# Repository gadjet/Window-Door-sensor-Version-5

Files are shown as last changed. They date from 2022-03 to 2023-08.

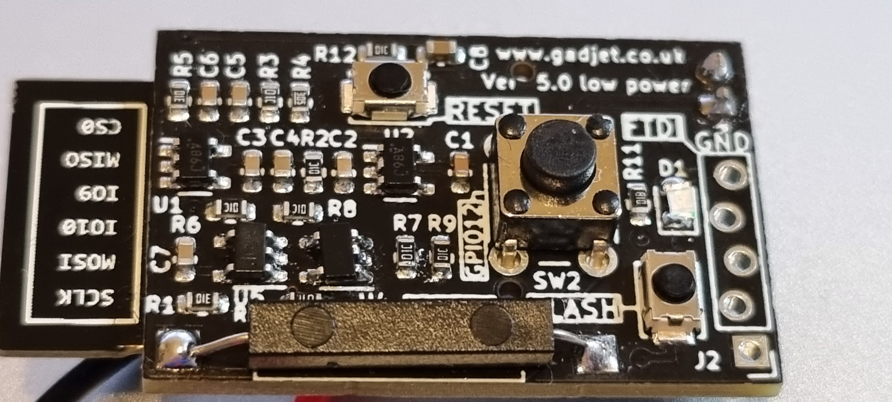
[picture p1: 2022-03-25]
V5_Assembled.jpg

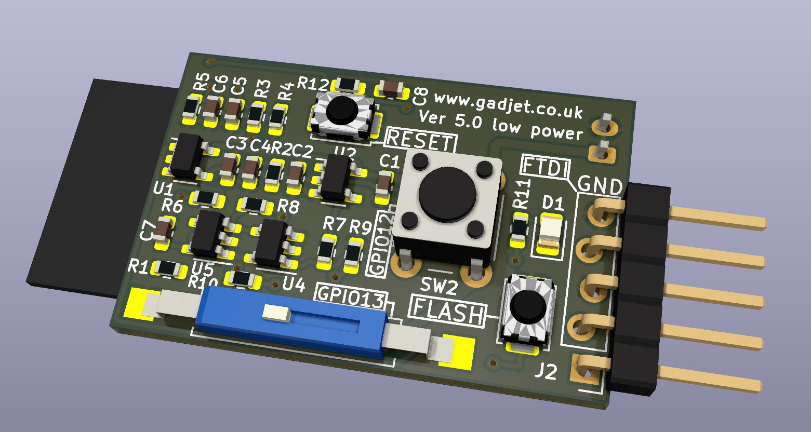
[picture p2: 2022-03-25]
3D render V5.jpg

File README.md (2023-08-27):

# Window-Door-sensor-Version-5

# I have found an error in the BOM file for the PCBA, U4 has the wrong LSC part number against it, I will correct the file ASAP
# The file has now been corrected 8/11/22

*** "Window sensor V5.zip" file added with all the files required for PCBA at JLCPCB.com previous files removed.

Version 5 of the Window/Door sensor project this time with ultra low current consumption and a button input.

I have continued to develop the original window/Door sensor from the Youtube video of Makermeik (https://github.com/MakerMeik) and this is the latest version (version 5)
At each revision I've tried to reduce the power consumption more and more and with this version the Quiescent current with the Door/Window shut is a around 5.4uA and with the door open or using as a WiFi button (Doorbell etc.) then it's around 3.9uA and depending on usage you're looking at years of usage on a small capacity L-ion cell.

The trigger logic is essetially the same as the the original version except the output from the two XOR gates is inverted to give a high pulse and return to Low when stable, this enables the output to trigger the input of an OR gate which self latches to keep the enable pin of the SPX3189 LDO high and the ESP module powered up.

When the ESP has finished running its code it sets GPIO16 low which resets the OR gates latch and powers off the LDO.

To keep the power on time as short as possible I'm using ESP-NOW to send the data packets to the ESP receiver but you could connect to your router and send MQTT messages, this would use more power but as the consumption is quite low the cell would still last quite a long time.

It has been pointed out to me that there are dedicated ICs out there that can handle this sort of thing, wake up from a button at least, but I can't find them readily available and the ones I can find are quite expesive, more than the cost of a populated Version 5 PCB from JLCPCB anyway.

# NOTE:
# It has been mentioned in the issues that my TX/RX labels are non standard, this is true the pin labelled TX is connected to the RX of the ESP and vice versa.
# I do this so when I plug in my flasher board the label match.

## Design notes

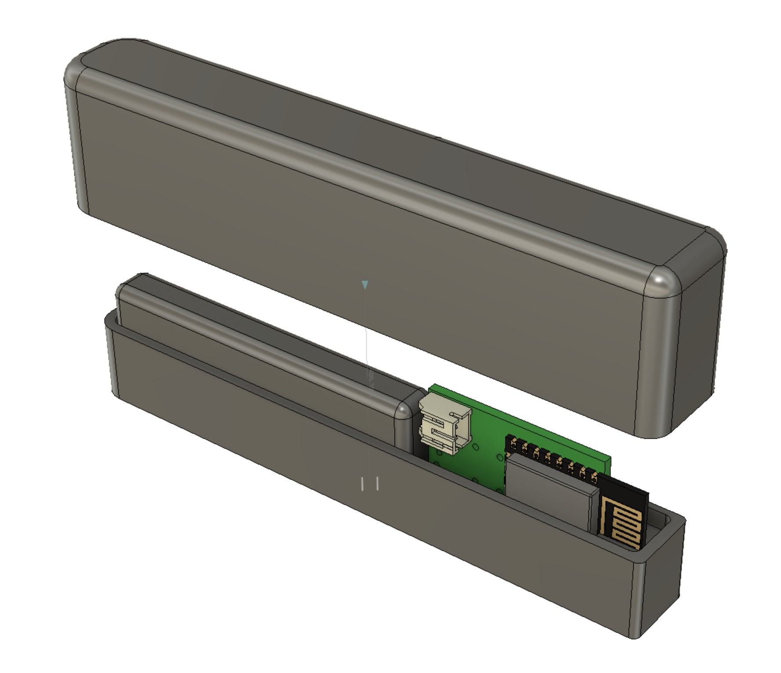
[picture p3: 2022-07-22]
Version 5 STL case design View.jpg

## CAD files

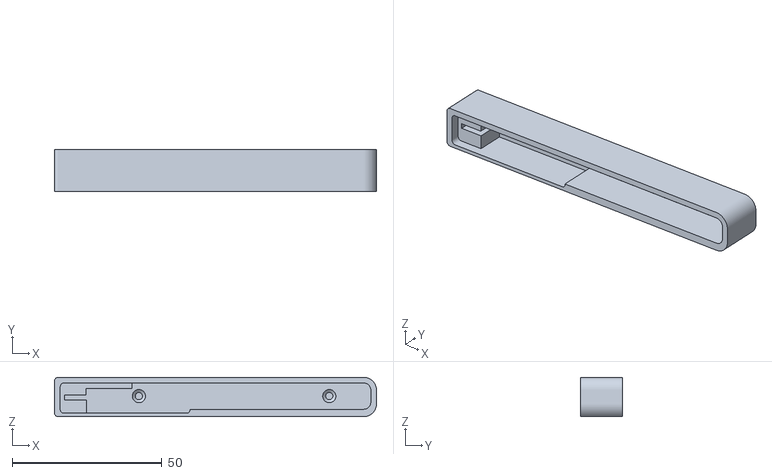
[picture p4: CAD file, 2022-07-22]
Version 5 Base.stl
107.5 x 14.0 x 13.2

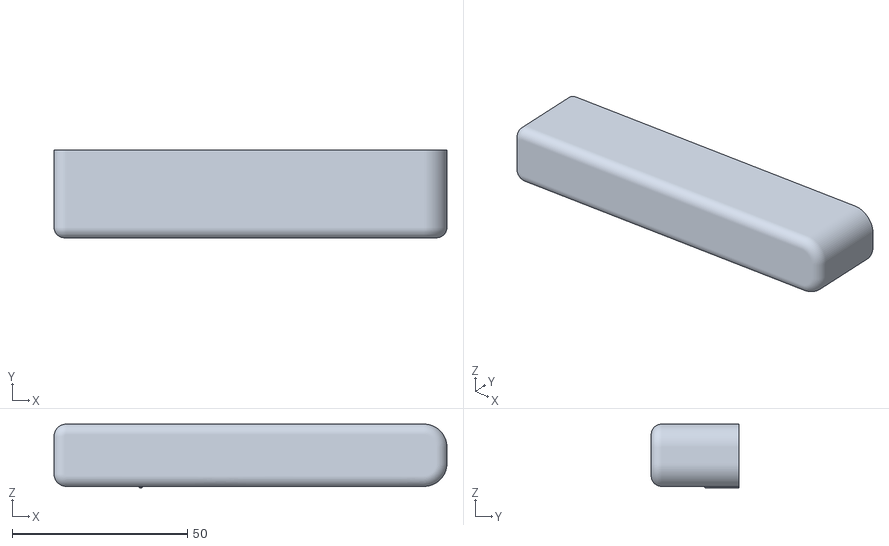
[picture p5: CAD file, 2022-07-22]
Version 5 Top Cover.stl
112.1 x 25.0 x 18.2

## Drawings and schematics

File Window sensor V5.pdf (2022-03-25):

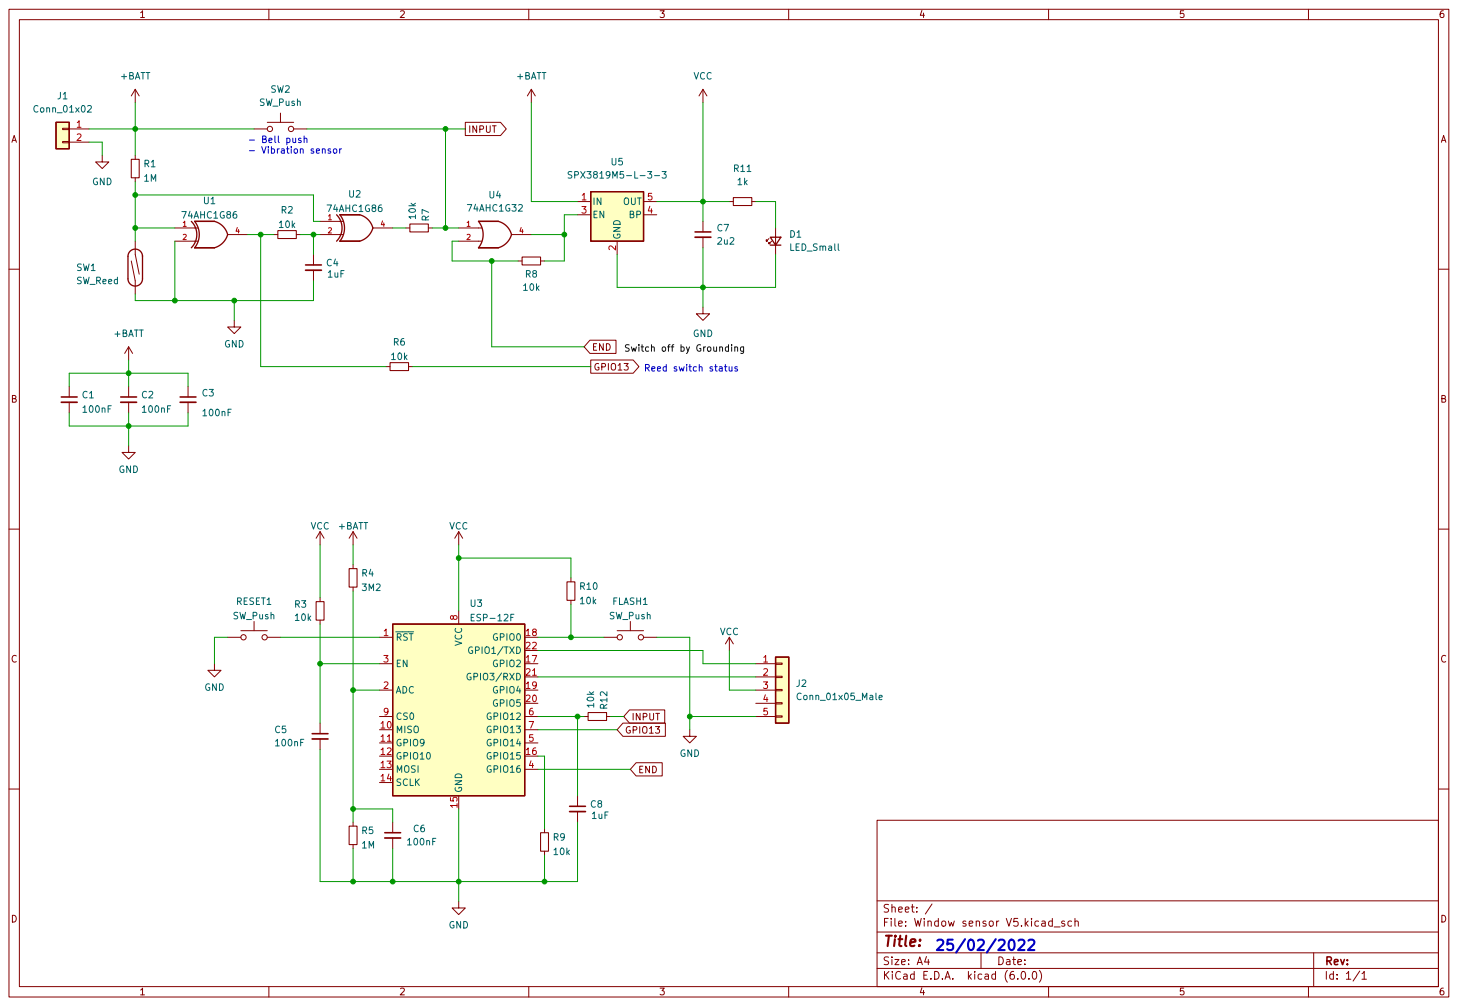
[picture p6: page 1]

INPUT END GPIO13 END Switch off by Grounding Reed switch status
100nF VCC

File: Window sensor V5.kicad_sch Sheet: /
Id: 1/1 Title:

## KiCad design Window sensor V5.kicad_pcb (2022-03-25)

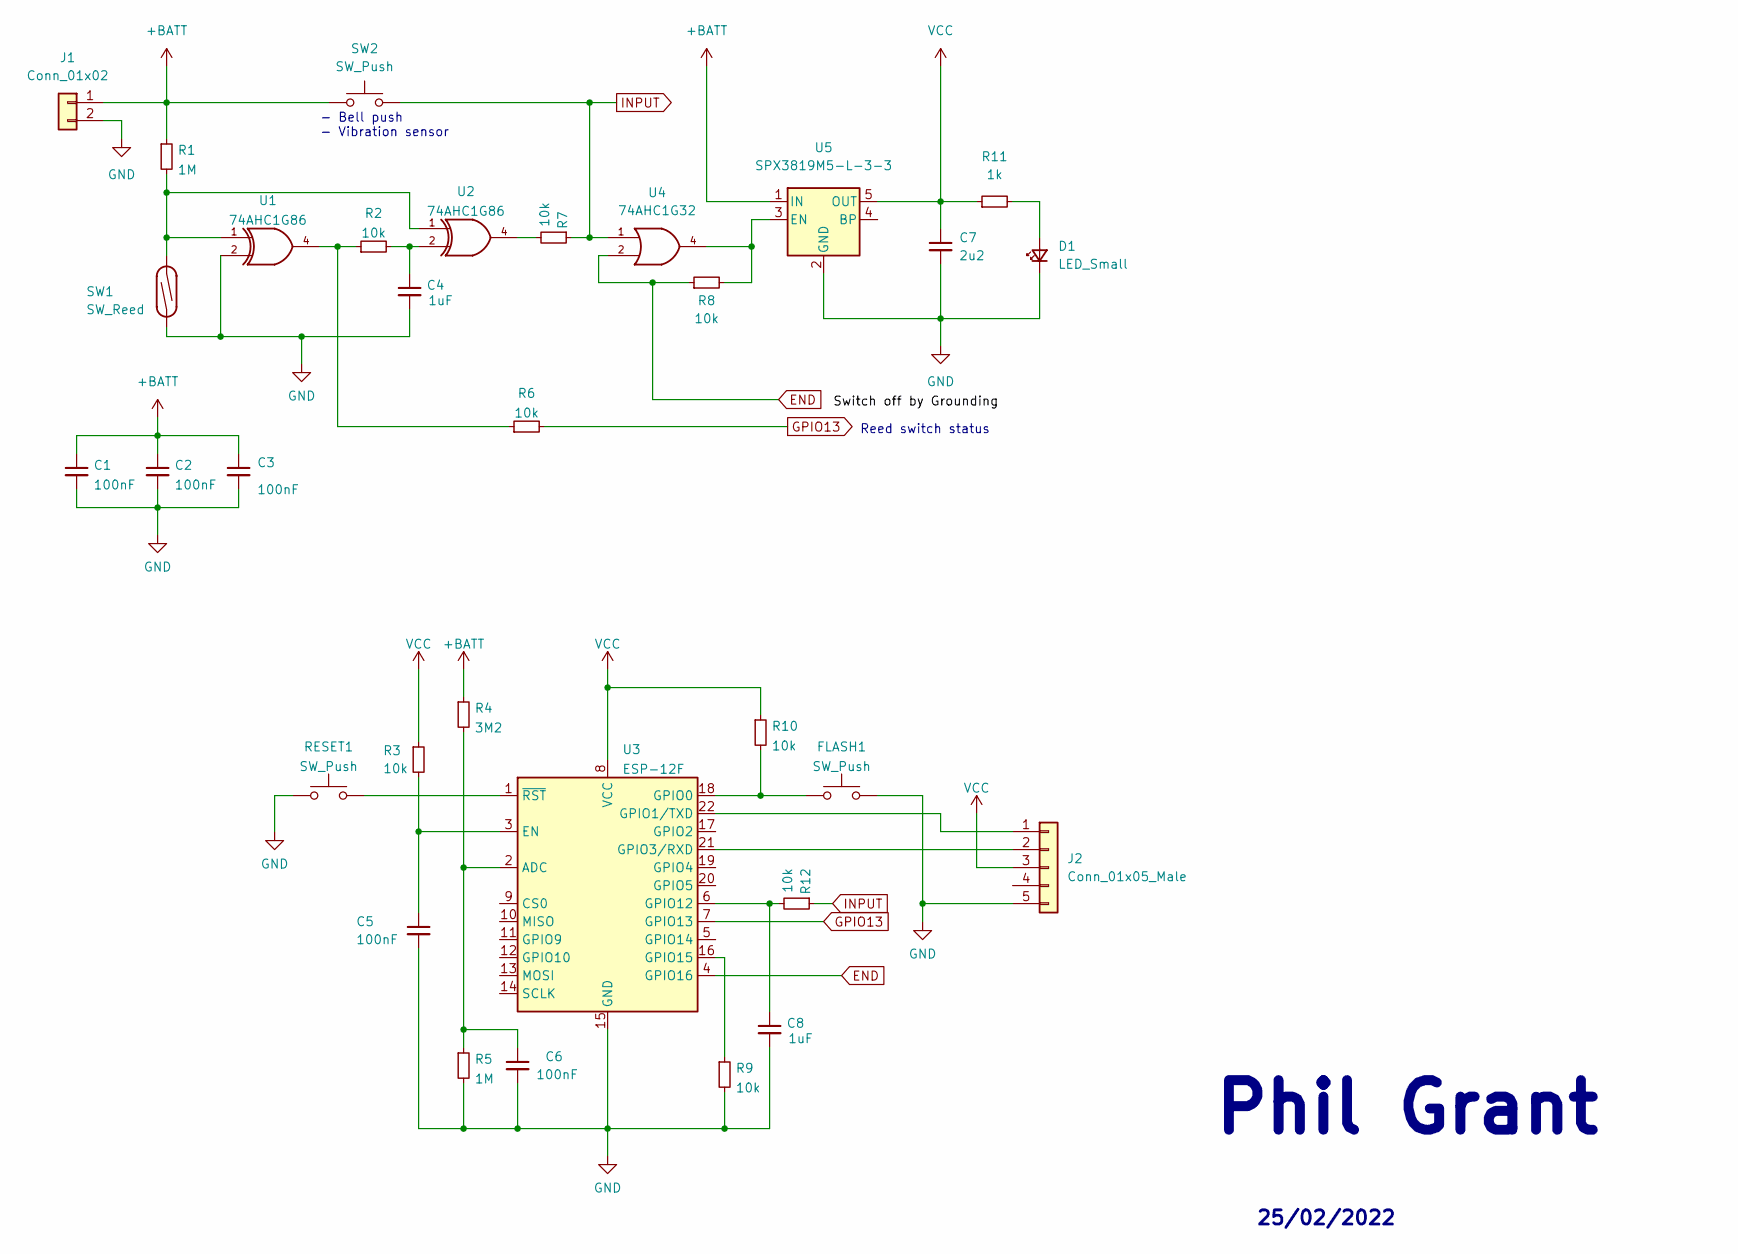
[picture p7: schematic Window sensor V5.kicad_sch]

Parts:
C1, C2, C3, C5, C6: 100nF; C_0603_1608Metric
C4, C8: 1uF; C_0603_1608Metric
C7: 2u2; C_0603_1608Metric
D1: LED_Small; LED_0805_2012Metric
FLASH1: SW_Push; SW_Push_SPST_NO_Alps_SKRK
J1: Conn_01x02; JST_PH_S2B-PH-K_1x02_P2.00mm_Horizontal
J2: Conn_01x05_Male; PinHeader_1x05_P2.54mm_Vertical
R1, R5: 1M; R_0603_1608Metric
R2, R3, R6, R7, R8, R9, R10, R12: 10k; R_0603_1608Metric
R4: 3M2; R_0603_1608Metric
R11: 1k; R_0603_1608Metric
RESET1: SW_Push; SW_Push_SPST_NO_Alps_SKRK
SW1: SW_Reed; SW_SPST_REED_CT10-XXXX-G2
SW2: SW_Push; SW_PUSH_6mm_H4.3mm
U1, U2: 74AHC1G86; SOT-23-5
U3: ESP-12F; ESP-12E
U4: 74AHC1G32; SOT-23-5
U5: SPX3819M5-L-3-3; SOT-23-5

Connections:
+BATT: C1.1, C2.1, C3.1, J1.1, R1.1, R4.1, SW2.1, U1.5 (+BATT), U2.5 (+BATT), U4.5 (+BATT), U5.1 (IN)
END: R8.1, U3.4 (GPIO16), U4.2
GND: C1.2, C2.2, C3.2, C4.2, C5.2, C6.2, C7.2, C8.2, D1.1 (K), FLASH1.2, J1.2, J2.5, R5.2, R9.2, RESET1.1, SW1.1, U1.2, U1.3 (GND), U2.3 (GND), U3.15 (GND), U4.3 (GND), U5.2 (GND); also elsewhere on the board
GPIO13: R6.2, U3.7 (GPIO13)
INPUT: R7.1, R12.1, SW2.2, U4.1
unnamed: C4.1, R2.2, U2.2
unnamed: C5.1, R3.2, U3.3 (EN)
unnamed: C6.1, R4.2, R5.1, U3.2 (ADC)
unnamed: C8.1, R12.2, U3.6 (GPIO12)
unnamed: D1.2 (A), R11.2
unnamed 10: FLASH1.1, R10.2, U3.18 (GPIO0); also elsewhere on the board
unnamed: J2.1, U3.22 (GPIO1/TXD)
unnamed: J2.2, U3.21 (GPIO3/RXD)
unnamed: R1.2, SW1.2, U1.1, U2.1
unnamed: R2.1, R6.1, U1.4
unnamed: R7.2, U2.4
unnamed: R8.2, U4.4, U5.3 (EN)
unnamed: R9.1, U3.16 (GPIO15)
unnamed 18: RESET1.2, U3.1 (~RST); also elsewhere on the board
VCC: C7.1, J2.3, R3.1, R10.1, R11.1, U3.8 (VCC), U5.5 (OUT)

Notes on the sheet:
- Bell push - Vibration sensor
25/02/2022
Reed switch status
Phil Grant

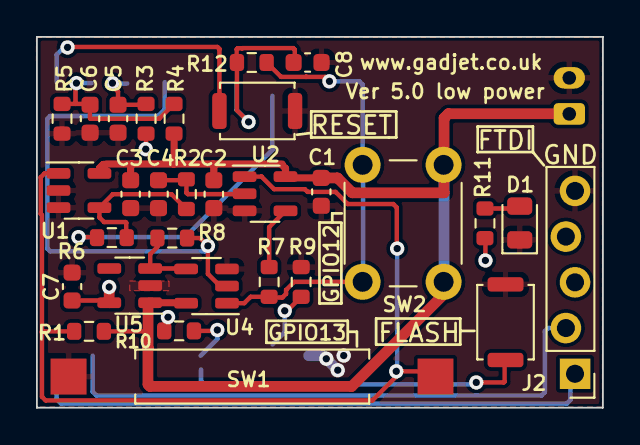
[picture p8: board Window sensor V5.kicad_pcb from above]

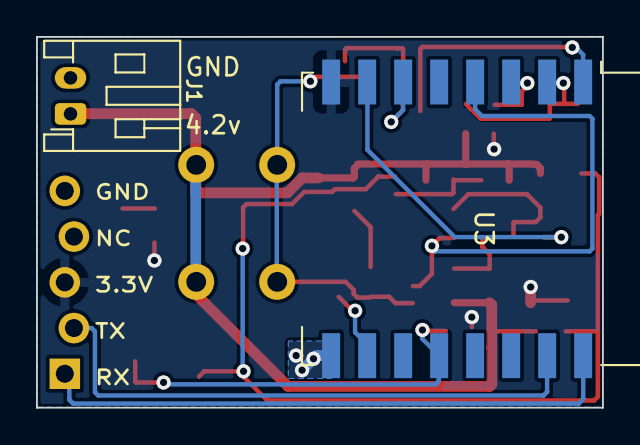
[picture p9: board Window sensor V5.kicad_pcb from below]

Board: 2 copper layers, 31.4 x 20.6 mm, 32 parts (2 on the bottom side), 20 nets.

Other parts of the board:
FLASH: SW_Push; SW_Push_SPST_NO_Alps_SKRK
RESET: SW_Push; SW_Push_SPST_NO_Alps_SKRK

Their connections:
GND: FLASH.2, RESET.1; also elsewhere on the board
unnamed 10: FLASH.1; also elsewhere on the board
unnamed 18: RESET.2; also elsewhere on the board

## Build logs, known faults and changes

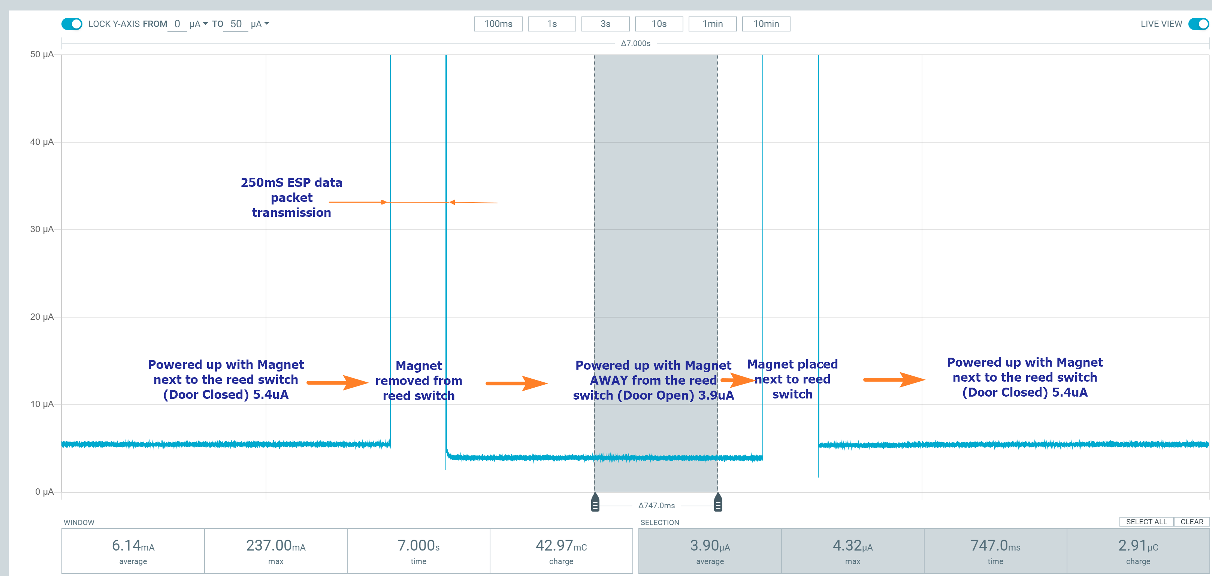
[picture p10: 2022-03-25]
V5 Quiescent current after fix.png

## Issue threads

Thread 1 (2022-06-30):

Help with esp8266 hanging

sheminasalam, 2022-06-30:
Hi there I have an issue with version 1 of this sensor. It would be good if you could help me out with it. My sensor can detect when the window is open without any issues. But when it comes to closing, it wont work all the time. I tried to diagnose the issue with serial monitor and found that when the window is being closed, the esp8266 starts to wake but before executing any functions, it hangs up. One more thing I noticed is that when this problem occurs the onboard led won't even blink like when the board boots up. But when we push the reset button(GPIO16) in closed state, the device boots fine and completes action and sleeps.

 Is this a code issue or some hardware issue? what can be the issue? I am confused because majority of the time this works fine.

gadjet, 2022-06-30:
Hi sheminasalam,
When you say version 1 do you mean this version (version 5)or the first project.

sheminasalam, 2022-06-30:
first project on which the youtube video was made

gadjet, 2022-06-30:
OK, to save confusion, can you raise the issue in the first version then so if others have the same problem they can see the issue in the right place :-) thanks.

gadjet, 2022-06-30:
The video isn't mine, I was inspired by the video to create my own version based on Maker Meiks

Closed 2022-06-30.

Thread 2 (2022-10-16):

ESP NOW to MQTT bridge

NeOdYmS, 2022-10-16:
it's not an issue just a question ;

i follow this project with attention since the start ^_^

can you give us more informations or a link about ESP NOW to mqtt

_i am manging all mys esp things with Home Assistant_

gadjet, 2022-10-16:
Hi,
My ESP-NOW receiver doesn't convert directly to MQTT although it could, I send the ESP NOW data via the USB connection from an ESP07 into the USB port of my raspberry Pi which runs Node Red, Node Red sends the data to the MQTT server. there are a few projects around showing how to send ESP NOW data to MQTT, try [](https://github.com/timmbogner/Farm-Data-Relay-System) for some ideas and examples

NeOdYmS, 2022-10-16:
thank you very much !

NeOdYmS, 2022-10-16:
and thank you for sharing your projects !
great job !

gadjet, 2022-10-16:
You're very welcome, I love it when someone uses or learns from what I do.

NeOdYmS, 2022-10-17:
also do you have the code of your  receiver ? to understand the message structure ?

gadjet, 2022-10-17:
I can add the receiver code later but the message structure is exactly the same as in the transmitter code.

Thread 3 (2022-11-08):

Wrong IC specified in the BoM

gadjet, 2022-11-08:
Unfortunately U4 in the original BOM file had the wrong part code against it, instead of calling for a single OR gate it called for a second LDO.
The old file has now been corrected and replaced so should be good to go.

If you have had some PCBs made then you will need to buy some 74AHC1G32 ICs and use a hot air tool or hot plate to change the U4 for one of these.

I'm sorry for any inconvenience caused :-(
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

NeOdYmS, 2022-11-16:
Argh i just received 25 of them
do y ou have the right ref ?

gadjet, 2022-11-16:
Sorry 😞
U4 should be an OR Gate.
See https://www.facebook.com/groups/1606743019578078/permalink/3035606703358362/
For more information

NeOdYmS, 2022-11-16:
no worry

I was planning to invest in a hot air gun station

Congrat's for this project !

I will give you some report when I will acheive all my set up

gadjet, 2022-11-17:
I bought a hot plate to fix mine, I hope it works OK when you change it :-) pleas let me know.

NeOdYmS, 2022-11-17:
hey i was searching on aliexpress and have a bit of hesitation between a hot plate or an air gun or perhaps the both in station
what reference did get

NeOdYmS, 2022-11-18:
i ordered 25 x 74AHC1G32DBVR from LCSC :
https://lcsc.com/product-detail/Gates_Texas-Instruments-SN74AHC1G32DBVR_C7470.html

just a comment ... : i opened the BOM file AND the Position File CSV's and the botth file are Right ...
i think more about a mistake from the JLPCB BOM importer ..

for the tools i am planning to order this :
https://fr.aliexpress.com/item/1005001711285885.html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

gadjet, 2022-11-18:
NeOdYmS,
The files on github are now correct, I modified them.
Phil

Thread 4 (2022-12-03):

Home assistant support (future request)

itsboo07, 2022-12-03:
Hi thanks for this wonderful project. How to get this work in home assistant without espnow hub. can you try to make this work on esphome instead? i know mqtt should do for now but hoping for some better ideas. and also try to make tutorial video and working in yt . this project is lit🔥 and needs many attention and popularity ❤️💯

gadjet, 2022-12-03:
Hmmm, ESPHome is a good idea but I'm not really experienced with ESPHome, all I've done is to set up an ESP Wemos D1 as a light level sensor.
Without the ESP hub I don't know what the message protocol would be to HA.

I will have a think about it.......see what can be done.

itsboo07, 2022-12-04:
thanks here are the reference of deep sleep in ESPhome. may be if you can help i can try.
https://esphome.io/components/deep_sleep.html

gadjet, 2022-12-06:
As it stands, version5 cannot be used inthe deep sleep mode as GPIO16 isn't connected to the reset pin so it can't wake itself up, the whole idea behind version 5 is that it is completely powered down in between being triggered to give a very long battery life.

The earlier versions (Version 3) of the sensor can be used in this way though so may be more compatible with ESP Home but the battery will not last nearly as long but if you use a full size 18650 you can still get a long run time.

itsboo07, 2022-12-08:
> As it stands, version5 cannot be used inthe deep sleep mode as GPIO16 isn't connected to the reset pin so it can't wake itself up, the whole idea behind version 5 is that it is completely powered down in between being triggered to give a very long battery life.
>
> The earlier versions (Version 3) of the sensor can be used in this way though so may be more compatible with ESP Home but the battery will not last nearly as long but if you use a full size 18650 you can still get a long run time.

thanks...instead can i use the same v5 circuit and instead of Espnow code...i will flash a mqtt or EPShome code which sends data and turns off by pulling LDO low. will this work?

gadjet, 2022-12-09:
Yes that should work although I don't know enough about ESPHome to say it will work but it probably will.

altacoon, 2022-12-20:
Am I right when assuming that deep sleep mode is no longer necessary as you power down the entire mcu?
Besides this I also would appreciate very much to see an ESPhome-flashed version 5.
You did a great job, thanks!

gadjet, 2022-12-20:
Thanks, that's right deep sleep isn't needed with V5 as it powers down completely.
ESP Home may be possible but I don't know enough about ESP Home to try it but wouldn't use it purely because I want it to last a long time on a small battery.

gadjet, 2022-12-21:
I asked the question on the home assistant forum about adding ESPHome
[HA Forum](https://community.home-assistant.io/t/esp-home-door-sensor-with-my-own-module/506004/3)

altacoon, 2022-12-21:
Good idea, thanks for this information. I keep my fingers crossed!

itsboo07, 2022-12-22:
thanks . i tried with esphome which takes nearly 7-9 secs to boot and send data. i would say mqtt is much better than esphome but espnow is the best. only problem of Espnow is i have 5 door in my house and all are very far from each other. so one espnow receiver won't help. soo stuck with mqtt.

altacoon, 2022-12-23:
Ok, not the fastest! But it depends on what you want to achieve. To monitor a window it is acceptable for me. @itsboo07, would you please share your ESPHome code?

gadjet, 2022-12-23:
> thanks . i tried with esphome which takes nearly 7-9 secs to boot and send data. i would say mqtt is much better than esphome but espnow is the best. only problem of Espnow is i have 5 door in my house and all are very far from each other. so one espnow receiver won't help. soo stuck with mqtt.

Great news, glad you got it working, it would be helpful too others if you could share you code, maybe even start you own github project?

itsboo07, 2022-12-26:
@gadjet sure i will try to share esphome code later. im trying to test espnow receiver in esphome.
can you check the below link and help  on how to set up receiver in esphome. do i need to make some changes in espnow transmitter device to make it compatible with esphome?
https://deploy-preview-775--esphome.netlify.app/components/wifi_now.html

altacoon, 2023-01-10:
I was lucky to find a very helpful guy on home assistant community to write some appropriate ESPHome code. The code is compiled quite well but flashing fails because there is no connection to the ESPHome servr on my raspi (see picture of log file):

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

Maybe I am mistaken in der flashing procedure, or I soldered the wrong connections to the pcb.

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

When flashing, I did not connect the external battery (a 9 V battery) to the pcb. Only 3,3V from the FTDI-Adapter is supplied.
I push (and release) the flash button once before flashing. I connected RX to RX and TX to TX (crossing is done on the pcb?!)

@gadjet, can you please check my flashing-setup and my flashing-procedure? What is the reason for the failure flashing?

gadjet, 2023-01-10:
Hi,
Some pointers to help:-
 - make sure you use an FTDI flasher that supplies 3.3v
 -  make sure the tx and rx are connected the right way FTDI rx to PCB tx etc.
 - press the flash button before you add connect the FTDI and keep it pressed until the ESP is powered up.
 - don't use external power supply while flashing

One other point, you mentioned powering fro a 9v battery, check the LDO can accept 9V input I can't remember what the spec. was

altacoon, 2023-01-10:
I checked the LDO before but did not for the logic gates, so they will be smashed. Then I have to solder the second pcb (I ordered 10). Ths issue but can not be the reason for the flashing issue, can it?

I just tried flashing again, keeping an eye on the points you mentioned in your previous post. It did not work.

gadjet, 2023-01-10:
One issue I've had in the past is the solder connections on the esp12 to the PCB, make sure they are good with a good magnifying glass

gadjet, 2023-01-10:
Does the blue LED on the Esp12 light up at all?

itsboo07, 2023-01-11:
> I just tried flashing again

looks like either esp is not powered or gpio0 is not pulled down to gnd. what I can recommend is you can you flash esp first before soldering to the pcb and later you can update code wirelessly. also try to use esphome legacy way of installation.
and more over to test first. try flashing a blink sketch with pin 2(pin 2 coz esp12 should have  boot led attached internally wth pin 2) in arduino ide and see if esp gets flashed and works.
I stopped working with esphome and instead made some working progress with espnow which is much better in less power consumption and very low latency (200ms) and boot time. esphome takes around 7 seconds.

gadjet, 2023-01-11:
Have you tried checking the continuity between the supply pins and ESP pads and made sure that whwn the flash button is pressed the GPIO0 is grounded?

altacoon, 2023-01-11:
I will follow all your points at the weekend.

Meanwhile please have a look at the ESPHome code from @mulcmu, which he has shared on home assistant community https://community.home-assistant.io/t/esp-home-door-sensor-with-my-own-module/506004/5?u=chincilla

gadjet, 2023-01-13:
I just checked the connections and pin 1 (square pad should be connected to the RX pin of your FTDI, in the picture you have labelled it RX so if that's RX of the FTDI then that's right.

altacoon, 2023-01-13:
Yes, I confirm. Because on the pcb this square pad is connected with GPIO1 (TX) of the ESP12. Thanks for clarification.

altacoon, 2023-01-13:
I am trying to flash the ESP12 separated from the pcb. But it turns out not to be so easy. I am struggling with my breadboard, additional wirings at the ESP with pull-up and pull-down resistors, flash button, reset-button and so on...
I found a source with good advices:
https://www.mischianti.org/2021/05/08/esp12-esp07-esp8266-flash-pinout-specs-and-arduino-ide-configuration-6/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
but it will take me some time to come back and report.

itsboo07, 2023-01-14:
@altacoon you don't need a 3d printed case to program esp12 separate instead you can use a 2mm berg male strip and solder jumper or necessary pins to the breadboard for required pull-up and pull down. also you don't need reset . you can just pull down gpio0 for programming and remove gpio0 from gnd and repower the esp.
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
gadjet, 2023-01-17:
My current solution is to have an ESP plugged into a raspberry pi running node red and then sending door status via MQTT (along with other sensor data) which is then picked up by HA running on another Pi, I plan to integrate it all on to one Pi when I get around to it.

Extending battery life was my primary goal.

altacoon, 2023-01-17:
@mulcmu, thank you for the detailed advice. I will then reduce the delay step by step. I understand ESP-NOW seems to be the faster solution, but for the time being I am very glad to have this project proceeded successfully so far- with your kind help, @gadjet and @mulcmu! I will now focus on modifying @gadjet's case, run the sensor in real life and observe the battery lifetime. I have to modify the case because I think of using two button coins 2032 als external power supply (let's see how long they work).
ESP-NOW stays in my brain, but as there is yet no simple HA integration, it will be a long road for me to built up a setup like gadjet describes.

gadjet, 2023-01-17:
Two 2032 cells !! you might get a few days depending on usage, have a look here to get a calculation https://battery-life.of-things.de/battery-life-calculator.php?_sm_au_=iVVs1n3SWZ18TfTFkj0BvKQs47RR6

altacoon, 2023-01-25:
Ok, this is not really satisfying. I will think about it. The LiPos you are using are currently out of stock, I only found this one  https://www.amazon.de/gp/product/B09NL3534F/ref=ewc_pr_img_1?smid=A1CTK3ECWVKPGM&psc=1
Perhaps I have to switch to 2 x CR123 batteries.

But by the way: Is your ESP-NOW setup depending on the ESP-cloud in any way or is it running in a completely local surrounding?

gadjet, 2023-01-25:
Hi, I have started to use Cells from discarded Vapes, a friend of my son gave me 20 used ones and I removed the cells, I have some 550mAH ones and some 1500mAH ones, I designed a new enclosure for the 550mAH Cell size.

ESP-NOW is purely a device to device protocol it doesn't even use the router so definitely a local communcation method and no cloud at all.

Roshi9, 2023-01-30:
Sorry to jump in this conversation like this, but i think it's a trivial task to create an esp receiver for esp now protocol, isn't it... I think it's then possible to make an integration with home assistant in some way. If using raspberry we can tie GPIO from esp to raspberry's gpio, power consumption is not an issue there since it's hooked up to raspberry. Serial communication is surely an option as well. It does require an additional board, but it's stupidly easy to make. Just assign different ID's to the various door sensors and expose them as serial binary sensors.

gadjet, 2023-01-30:
Yes, I just plug an ESP07 with extrernal antenna into the USB of the Pi and then use Node red to convert data to MQTT messages which I then pickup with HA.

altacoon, 2023-02-07:
I am running the window sensor now with a 850 mAh-Lipo battery. It fits in your box (with small modifications).
It turned out, that the ESPhome code leads to a problem: I reported that the sensor needs about 10 s to go online then pushes his information and finally shuts down after 25 to 30 s. The state change of the reed switch within this 30 s-period is not transmitted to ha. (@mulcmu, you did foresee this in a previous post).

Does anybody has an idea how to solve this?

altacoon, 2023-02-07:
Could solve this meanwhile by adequate configuring a template binary sensor, triggered by state change.

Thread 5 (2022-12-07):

MQTT CODE SUPPORT

VarunKumaran, 2022-12-07:
Hiiii there!!! I really love your low device and would like to do the same using only MQTT to send a message to my MQTT broker(raspberry Pi) when ever the state of the door sensor changes... Can you please help me with the code for MQTT??

And secondly can u please explain the calculation part for the battery voltage value

`myData.vBatt` = (analogRead(A0) * 4.2 * 10 / 1023);`

gadjet, 2022-12-07:
Hi,
You can take any MQTT sketch example and use it so that it sends the message and then just remember to set GPIO16 to switch off the supply when you've finished.

I assume you're aware that it will use more battery power sending MQTT via your router and take longer, around 7 seconds, to send the message.

The ADC read takes the value from ADC(0) and converts it to an integer value by multiplying it by a factor of ten then divde it by 10 when you deal with the received message, i.e. a value of 600 from the ADC would be aout 2.46V but using the calculation above the message sent would be 24.

steelsparky, 2022-12-07:
I'll confirm what Gadjet is saying - you want espnow first. The delay to connect upon startup and then publish is too long.. when the window sensor is off it's disconnected from Wi-Fi so when it wakes up it needs to reconnect. I have a work around though using two d1's acting as a gateway - one as a esp-now receiver and the other that's always connected to mqtt which will publish the topic. There's a total of 3 sketches; the window sensor, the espnow slave, and mqtt gateway. I'm also using node-red to notify/alert to a Sonos device using tts. It's been working great. I'll see if I can put this all together soon to share.

thematrixincendies, 2023-08-27:
For anyone reading this and asking themselves why this weird calculation for the input voltage happens:

- **Why divide by 1023?**
The ADC pin of the ESP12 only operates at a range of 0 to 1V and in software it gives you a 10 bit unsinged value, so 0 to 1023.
Thus, if you read for example 345, the input voltage is: 345 / 1023 ~ 0,337V.
- **Why multiply by 10?**
As gadjet explained above, that is apparently his way of putting a decimal number into a non-decimal number. By multiplying by 10 and then converting to integer, you'll keep one decimal. Obvioulsy, you need to transform it back after receiving the value.
- "Why multiply by 4.2V?"
Well, to measure any voltage higher than 1V, you need a voltage divider, i.e. you need to bring your maximum voltage down to 1V. That is exactly what gadjet did in this design. ADC connects to a voltage divier formed by a R1 = 3.2MOhm and a R2 = 1MOhm resistor. The output voltage at VDC (in the middle of the voltage divider) is V_in * R2 / (R1+ R2). Notice, that because of the fraction all factors of 10 for the resistor values cancel each other out. So, the same result could have been achieved with 320Ohm and 100Ohm or 3.2kOhm and 1kOhm resistors. I guess the high resistances were chosen to limit the current going into ADC. Anyway, 100/(100+320) = 1/4.2, thus this voltage divider maps the range of 0 to 4.2V to 0 to 1V. So, to reverse this mapping in the software, you multiply by 4.2. Note that this assumes you use a battery whose maximum voltage at 100% is 4.2V.

gadjet, 2023-08-27:
thematrixincendies
Thanks for the detailed explanation, the main reason for the high resistance of the potential divider network is to reduce the quiescent current drain on the battery as it is permanently connected.

wilriker, 2025-01-16:
I stranded here looking for a reason why I see unexpectedly high values on ADC. I measure my battery with a regular multimeter at a little over 3.8V. Still, the ESP always reads a value very close to 1V (`adc_read` - I ported the code over to ESP8266 RTOS - returns values around 1000) so it always sends 41/42 over ESP-NOW.

When measuring the voltage with the multimeter at the ADC pin I see a (at least to me) rather strange behavior: it starts out at a value around 0.5V and then slowly drops the longer I measure until it gets to somewhere around 0.375V. So maybe that effect of seeing an initial larger value (the multimeter takes a few seconds to display the initial value) is even increased for the ESP after startup?! Any ideas here?

P.S.: I tried to move reading the ADC to the last possible moment, also tried using `adc_read_fast` and read the ADC 100 times, taking only the last value but that made no difference. Neither did artificially delaying reading the value for 2 seconds.

P.S.: sorry for hijacking the ticket. ;-)

gadjet, 2025-01-16:
wilriker,
I'm not sure what's going on with your readings but my battery level is basically working and I know when to change the battery, it drops over time from 4.2v to 3.1V.

Due to the tolerance of resistors etc. tere will always be some variance in the actual voltage at the ADC pin, in other projects I've used some code to calibrate the reading to match the real level of the battery.

Something else I do is take 10 readings of the battery and divide the result by 10 to get an average voltage reading, the number of reading s and time between readings is adjustable in code.

If you have a battery voltage of 4.2V and see 0.5V at the ADC input then there is something wrong with your potential divider network or the multimeter has a low internal resistance maybe?
Check the resistor values are what they should be, 3M and 1M maybe there's a problem with them.

wilriker, 2025-01-16:
Resistor values are the actual problem. While R5 has 0.991M and this is rather close to what needs to be there R4 is only 2.64M and that is significantly lower than required. Putting those values in the current calculation explains the "false" values read by the ADC as they are totally correct this way. I'll contact JLCPCB and see what they say about that.

Thanks, that was the missing hint.

gadjet, 2025-01-16:
That still doesn't sound right

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

wilriker, 2025-01-16:
It might not explain the strange readings with my multimeter directly in the ADC pin but it perfectly explains the ADC readings in firmware since with this voltage divider the 1V at the ADC pin is already reached at 3.66V battery voltage - and all my batteries are currently around 3.85V.

gadjet, 2025-01-16:
Yes it would.

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

--
Regards,
Phil
www.gadjet.co.uk <http://www.gadjetsblog.blogspot.com>
www.mylathe.uk

wilriker, 2025-01-17:
I've contacted JLCPCB now. The resistors are supposed to be 3MΩ ±1% and with their actual 2.65MΩ they are nearly 12% under. Let's see what they come back with.

wilriker, 2025-01-17:
Now, this is getting more mysterious by the second (or probably it's just my lack of deeper knowledge in electrical engineering):
I wanted to file a quality complaint at JLCPCB and as part of that I wanted to created a picture of my multimeter showing that the resistance is in fact way lower than expected. To make this easier for me I switched my indiviual probe leads to a tweezer-style test clip. And suddenly the resistor was measured at the expected 3MΩ.

Fiddling back and forth with multiple sets of probe leads and the tweezer-thingy I found out that the resistance value depends on which side of the resistor I put the COM lead and which side the positive lead.

When I have positive on the `+BATT` and COM on the `ADC` side it reads 3MΩ, when switching the leads I get only the 2.65MΩ. I guess this has something to do with `C6` capacitor that then confuses the multimeter. Could this be? And if so: would this not also confuse `ADC` readings? 🤔

wilriker, 2025-01-17:
Yeah, I think I can go forward from here adjusting the multiplier in code from `4.2` to just `4` since that is what the sum of the resistors actually is and then I should be good to go.

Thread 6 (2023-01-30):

Suggestions to reduce cost/consumption

Roshi9, 2023-01-30:
Hello gadjet,

not knowing any other way to contact you i am going to use the issues function. I think that price-wise using jumpers instead of buttons (which i found being quite pricey) can further reduce the overall cost.
This being said, in your BoM you do not include the battery connector, which imho should be there.

Also, as a further project developement i think it would be possible to:
- create a PIR motion sensor with the same principle of this door sensor, changing very little in the schematics
- use esp32 to lower power consumption, given the light sleep is used. Find an energy consumption comparison between esp8266 and eps32 here: https://blog.voneicken.com/2018/lp-wifi-esp-comparison/
I am no expert nor professional, just used to work a bit in the industry and love tinkering with diy electronics so feel free to correct me if i am wrong.

gadjet, 2023-01-30:
Hi Roshi9,
No problem, I have to admit I wasn't really to concerned with the overalll cost of a board as when ordering as a PCBA the cost of the buttons was only a few pence, if you order them from ebay to build your own then they will be a bit motre expensive.
I didn't include any through hole components in the BoM as it was used for the PCBA order and the battery connector was through hole so I could use some I already had or use wires to connect to a cell.

- As for the PIR, you can probably use one of these https://learn.adafruit.com/pir-passive-infrared-proximity-motion-sensor and feed the trigger signal into the switch input to trigger the Power-up of the circuit, not sure if there would be any timing issues?
- The ESP power consumption doesn't matter as the whole ESP is powered down when not triggered, the only current consumption between triggers is the quiescent of the LDO and monitoring logic, around 4 - 5uA.

I hope you are succesful at getting it working and please continue to give feedback and make suggestions :-)

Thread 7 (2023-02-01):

Powering GPIO INPUT pins with 4.2V

ss7799166340, 2023-02-01:
The logic gates work on battery, assuming it to be a LIPO, we will be directly feeding the 4.2V directly to INPUT & GPIO pins. Isn't that an issue in the long run for the MCU.

gadjet, 2023-02-01:
I have been running mine on a door for a good few months now without any issues and I think the series 10K resistors will limit current.

I did find a post on an ESP8266 Facebook group supposedly from the CEO Teo Swee Ann stating that as long as the ESP was supplied with 3.3V then the inputs would tolerate 5V and many people agreed.

Also don't forget that if you use ESP-NOW then it will only power up for 200 -300mS

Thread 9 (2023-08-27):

Re-label RX and TX

thematrixincendies, 2023-08-27:
Currently, the markings on the PCB read "TX" and "RX". The problem is, that the pin labeled "RX" actually connects to the ESP's "TX" pin and the pin labeled "TX" actually connects to the ESP's "RX" pin".
I guess this was done to be able to connect "TX" of a flasher to "TX" on the board and the same for the "RX" pin.
However, no board does this and it is counter intuitive.

gadjet, 2023-08-27:
Hmm, you are right but to be honest I do it so that I can just plug my USB to Serial flasher PCB straight on to it and the labels match, afterall it's my design ;-)

thematrixincendies, 2023-08-27:
Sure, it's your design. You might at least want to add a note to the readme, because, trust me, nobody expects this.

thematrixincendies, 2023-08-27:
Ah, you already did, thanks!

Closed 2023-08-27.

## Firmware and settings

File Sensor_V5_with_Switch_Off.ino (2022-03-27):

#include<ESP8266WiFi.h>
#include<espnow.h>


uint8_t bridgeAddress1[] = {0xNN, 0xNN, 0xNN, 0xNN, 0xNN, 0xNN};   //please update this with the MAC address of your ESP-NOW TO MQTT brigde
//uint8_t bridgeAddress2[] = {0xNN, 0x4NN, 0xNN, 0xNN, 0xNN, 0xNN};   //please update this with the MAC address of your ESP-NOW TO MQTT brigde

// Set your Board ID (ESP32 Sender #1 = BOARD_ID 1, ESP32 Sender #2 = BOARD_ID 2, etc)
#define BOARD_ID 20

const int reedSwitch = 13;
const int powerOff = 16; // set to low to turn off LDO

// Structure example to send data
// Must match the receiver structure
typedef struct struct_message {
  int id;
  char state[7];
  int vBatt;
  float Temp;
} struct_message;

// Create a struct_message called test to store variables to be sent
struct_message myData;

// Callback when data is sent
void OnDataSent(uint8_t *mac_addr, uint8_t sendStatus) {
  /* Serial.print("\r\nLast Packet Send Status: ");
    if (sendStatus == 0){
     Serial.println("Delivery success");
    }
    else{
     Serial.println("Delivery fail");
    }
  */
}

void setup() {
  // Init Serial Monitor
  //Serial.begin(115200);
  // initialize the reed switch pin as an input:
  pinMode(reedSwitch, INPUT);
  // initialize the wakeup pin as an input:
  pinMode(powerOff, OUTPUT);
  digitalWrite(powerOff, HIGH);
  // Set device as a Wi-Fi Station
  WiFi.mode(WIFI_STA);
  WiFi.disconnect();

  // Init ESP-NOW
  if (esp_now_init() != 0) {
    //Serial.println("Error initializing ESP-NOW");
    return;
  }
  // Set ESP-NOW role
  esp_now_set_self_role(ESP_NOW_ROLE_CONTROLLER);

  // Once ESPNow is successfully init, we will register for Send CB to
  // get the status of Trasnmitted packet
  esp_now_register_send_cb(OnDataSent);

  // Register peer
  esp_now_add_peer(bridgeAddress1, ESP_NOW_ROLE_SLAVE, 1, NULL, 0);
  esp_now_add_peer(bridgeAddress2, ESP_NOW_ROLE_SLAVE, 2, NULL, 0);
}

void loop() {
  // Set values to send
  myData.id = BOARD_ID;
  // Read the state of the reed switch and send open or closed
  if (digitalRead(reedSwitch) == HIGH) {
    strcpy(myData.state, "Open");
  }
  else {
    strcpy(myData.state, "Closed");
  }

  myData.vBatt = (analogRead(A0) * 4.2 * 10 / 1023);
#ifdef useTempDS18B20
  myData.Temp = sensors.getTempC(Thermometer);
#elseif #elseif useAHT10 || seBME280
  myData.Temp = sensors.getTempC(Thermometer);
  myData.Humid = 0.0; //sensors.getTempC(Thermometer);
#endif

  // Send message via ESP-NOW
  esp_now_send(0, (uint8_t *) &myData, sizeof(myData));
  //ESP.deepSleep(0);
  delay(100);
  digitalWrite(powerOff, LOW); //Switch off supply
}

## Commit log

2022-03-25 Add files via upload
    Sensor code to send data packet via ESP_NOW and switch off the power.
    Needs to be used with a ESP configured as a Receiver/Gateway.
2022-03-27 Update Sensor_V5_with_Switch_Off.ino
    Swapped open and closed status to match reed switch
    [Sensor_V5_with_Switch_Off.ino]
2022-03-27 Add files via upload
    Zip file with gerber files for PCB production, please chaeck the gerbers before ordering.
    [Window sensor V5-B_Cu.gbr, Window sensor V5-B_Mask.gbr, Window sensor V5-B_Paste.gbr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]
2022-07-21 Add files via upload
    3D model exported from KiCAD
2022-07-22 Add files via upload
    Top and bottom case STL files for version 5
    [Version 5 Base.stl, Version 5 Top Cover.stl]
2022-07-22 Add files via upload
    3D rendering of the two STL files for the Version 5 3D printed case
2022-07-26 Add files via upload
    Use these files to get the PCBs made, including a BoM file and Component position file
2022-07-26 Delete Files for Production directory
    Files removed and replaced with "Window Sensor V5.zip" file
    [Window sensor V5-B_Cu.gbr, Window sensor V5-B_Mask.gbr, Window sensor V5-B_Paste.gbr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]
2022-07-26 Add files via upload
    PCB Production files
2022-07-26 Delete Window sensor V5updated BOM.csv
    Replaced with Window sensor V5.zip file
    [Window sensor V5updated BOM.csv]
2022-11-07 Update README.md
    Added image of PCB
2022-11-08 Delete Window sensor V5.zip
    File removed as it's a duplicate file
2022-11-08 Add files via upload
    Corrected BOM file for the OR gate IC
2023-09-13 Update BOM file to include D1 Line item
